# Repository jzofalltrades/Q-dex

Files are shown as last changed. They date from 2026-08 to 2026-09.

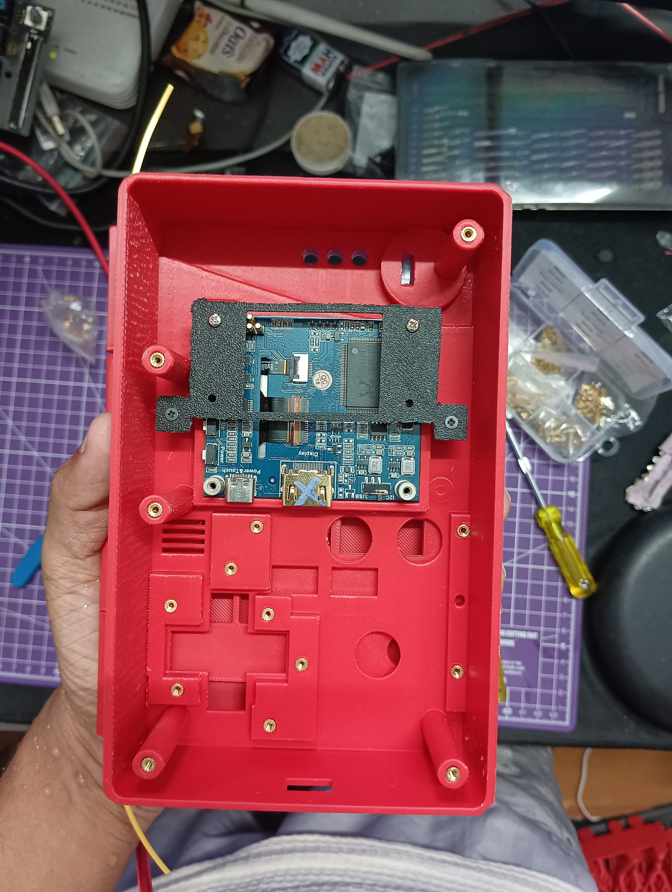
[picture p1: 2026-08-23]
images/build-backpanel-inserts.jpg

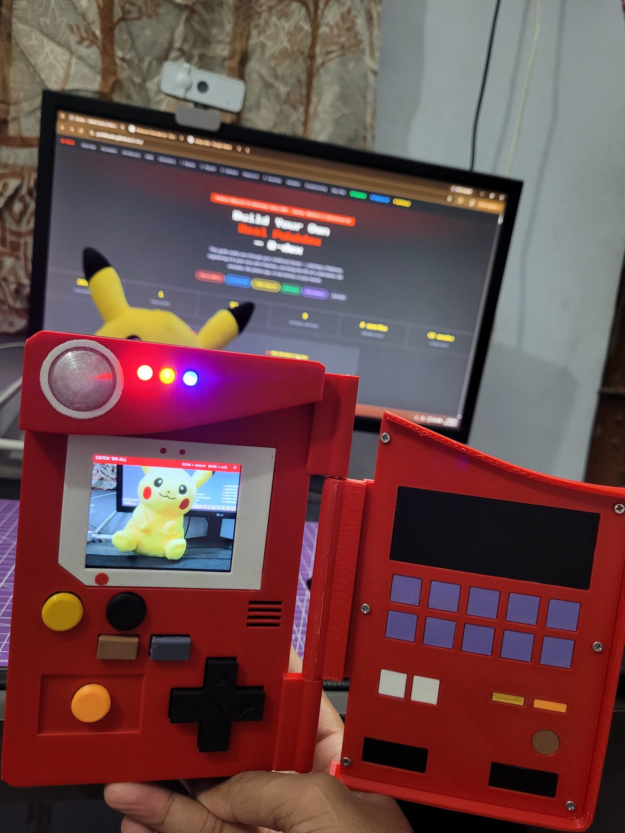
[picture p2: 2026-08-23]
images/mode-reverse-camera.jpg

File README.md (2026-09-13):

# Q-dexter — A Real Handheld Pokédex

A fully working handheld Pokédex built on the **Arduino UNO Q**, for the
**Arduino Physical AI Challenge India 2026**. Point it at a Pokémon, press
scan, and it identifies the creature, shows its Pokédex entry, speaks its
name, and logs the catch — with on-device AI, a voice assistant, and a
3D-printed Gen-1 Kanto shell.

### 🔗 Live pages
- **[📖 Full Build Guide](https://jzofalltrades.github.io/Q-dex/)** — the complete, illustrated how-to
- **[🎮 3D Model Viewer](https://jzofalltrades.github.io/Q-dex/viewer.html)** — rotate the enclosure in your browser

---

## What it does

- **Reverse Image Version** — camera capture → Google Lens → identifies any of
  the **1025 Pokémon**, shows stats/evolution/moves/location, speaks the entry,
  and records the catch.
- **PhyAI Challenge** — an **on-device** neural network (MobileNetV2, runs with
  no internet) that recognises four Pokémon (Bulbasaur, Charizard, Pikachu,
  Squirtle) live from the camera.
- **Professor Oak voice assistant** — ask questions out loud; on-device
  speech-to-text (whisper.cpp) → Claude → spoken reply. Knows your trainer
  profile and real catch progress.
- **Trainer system** — profiles, XP, levels, and **72 gym badges** across all
  9 regions, with region unlock gating.
- **Physical build** — 3D-printed Kanto-red shell, physical keypad, indicator
  LEDs, a blinking lens LED, and a real speaker.

## How it works

The device is an Arduino UNO Q (embedded Linux) running a pygame app, with an
ESP32-C3 handling the physical keypad and lens LED over USB serial. A camera
feeds both the online reverse-image path and the offline on-device classifier.
Audio is spoken through espeak into a PAM8403 amp and speaker.

```
Camera ─┬─► Reverse Image Version ─► Google Lens ─► Pokédex entry ─► speak + log
        └─► PhyAI (on-device model) ─► live identification

Mic ─► whisper.cpp ─► Claude ─► Professor Oak reply ─► speak
```

Full architecture, schematics, bill of materials, wiring, print settings, and
step-by-step build phases are in the **[Build Guide](https://jzofalltrades.github.io/Q-dex/)**.

## Repository layout

| Path | What it is |
|---|---|
| `pokedex_app.py` | The main pygame Pokédex application |
| `key_serial.py` | Host-side reader for the ESP32 keypad + LED forwarding |
| `keypad_serial.ino` | ESP32-C3 firmware (keypad + WS2812 lens LED) |
| `pokedex_phyai.tflite` | On-device Pokémon classifier (TFLite) |
| `labels.txt` | Class labels for the on-device model |
| `badges/` | All 72 gym-badge images, by region |
| `build_db.py`, `build_locations.py` | Database build scripts |
| `index.html`, `viewer.html` | The build-guide website and 3D viewer |
| `models/` | 3D model of the enclosure (`.glb`) |
| `cad/` | Fusion 360 / STL enclosure files |

## Hardware

Arduino UNO Q · ESP32-C3 Super Mini · USB camera · PAM8403 amplifier + speaker ·
WS2812 LED · indicator LEDs · 3D-printed enclosure. Full BOM in the build guide.

## License

This project's code and designs are released under the MIT License — see the LICENSE file. You're free to build your own, modify it, and share it, with credit.

**Non-commercial fan project.** Pokémon and all related names, data, and cries are trademarks of Nintendo / Game Freak / The Pokémon Company. Q-dex is an independent fan project, not affiliated with or endorsed by Nintendo, and may not be sold commercially.

## Built by

[jzofalltrades](https://github.com/jzofalltrades) — solo entry, Arduino
Physical AI Challenge India 2026.

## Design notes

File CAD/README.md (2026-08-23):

# Q-dex — CAD Files

3D-printable enclosure for the Q-dex handheld Pokédex, designed in Autodesk Fusion 360.

## Files

| File | Purpose |
|---|---|
| `STL/` | Ready-to-print meshes — load straight into your slicer. |
| `pokedexV4.step` | Editable, software-neutral CAD — open and modify in any CAD program. |
| `pokedexV4.f3d` | Original Fusion 360 project with full design history. |

## Parts (STL folder)

**Main body & lid**
- `LeftTub.stl` — main front body; holds the display, ESP32 keypad and buttons
- `BackPlate.stl` — back panel; mounts the Arduino UNO Q (brass-insert bosses)
- `RightLid.stl` — the right-hand lid of the clamshell
- `LidFacePlate.stl` — face plate for the lid
- `ScreenBezel.stl` — frames the 2.8" display
- `LCDCrossPlate.stl` — internal display support plate

**Buttons & caps**
- `Cap_DPad.stl` — one-piece D-pad cross cap
- `Cap_btn9.stl`, `Cap_Select.stl`, `Cap_Back.stl` — action-button caps
- `Cap_pillA.stl`, `Cap_pillB.stl` — pill-shaped button caps

**Lens**
- `Dome_Ring.stl` — ring that holds the clear dome lens (print the lens itself in clear PETG)

**Right-panel dummy inserts** (cosmetic, non-functional — they fill the decorative right panel)
- `DummyBtn_Mute_rightpanel.stl`, `DummyKey_rightpanel_x10.stl`, `DummyPill_rightpanel_x2.stl`,
  `Dummy_Screen_Right panel.stl`, `Dummy_bottom_rectangle_rightpanel_x2.stl`,
  `Dummy_bottomsquare_x2_rightpanel.stl`

## Print settings

- **Material:** PLA for every part **except** the dome lens, printed in **clear PETG** so the WS2812 lens LED shines through.
- **Layer height:** 0.20 mm for all parts.
- **Total print time:** approximately 25+ hours across the full set.
- **Hinge:** printed-in — there is no separate metal hinge pin.
- **Inserts / screws:** M2 and M3 brass heat-set inserts; screws M2×3 / M2×6 / M2×8 to match.

Print one button cap and its matching hole first as a quick fit test before committing to the long shell prints.

## Assembly

See the full build guide at **https://jzofalltrades.github.io/Q-dex/** (Phase 4 — Print & Assembly) and the interactive 3D model at **https://jzofalltrades.github.io/Q-dex/viewer.html**.

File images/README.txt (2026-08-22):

Q-dexter product photos — build shots, final device, screens in action.

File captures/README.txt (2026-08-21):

Camera captures are uploaded here at runtime for Google Lens recognition.

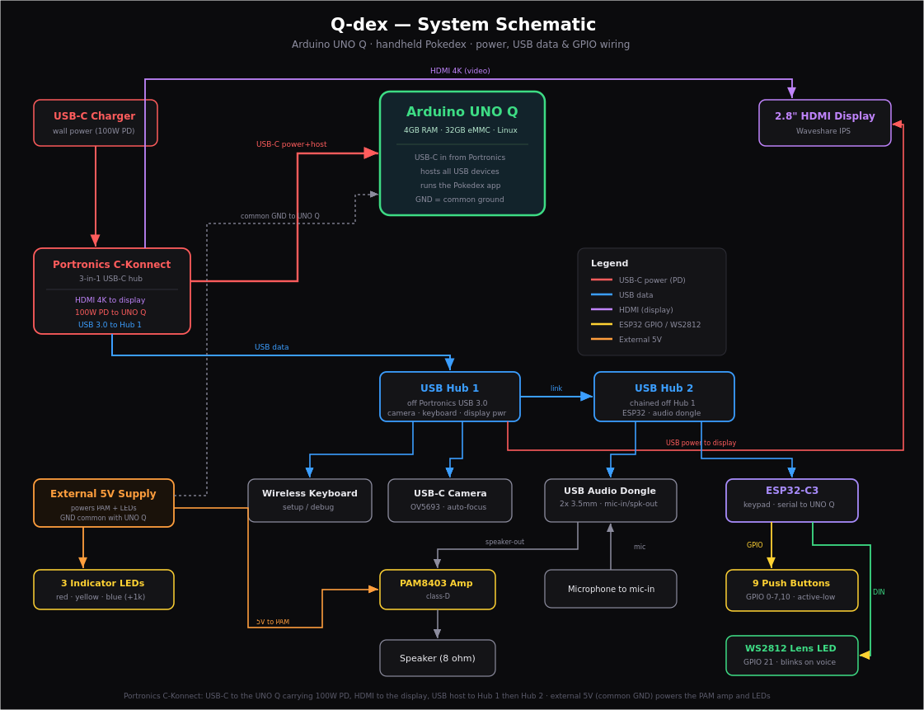
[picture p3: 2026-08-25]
images/qdex_schematic.png

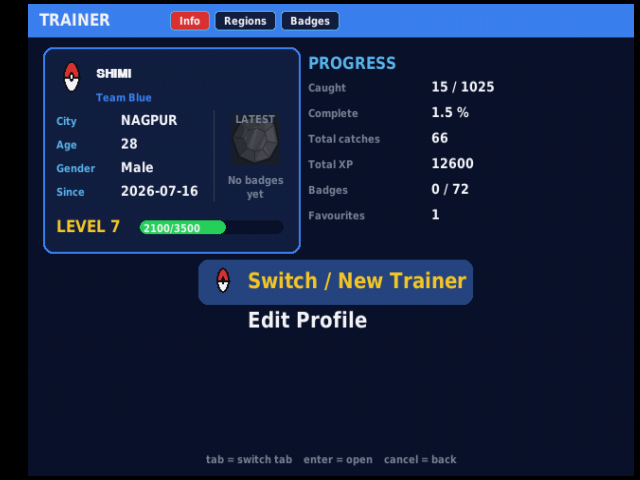
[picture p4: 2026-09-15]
images/screens/trainer-info.png

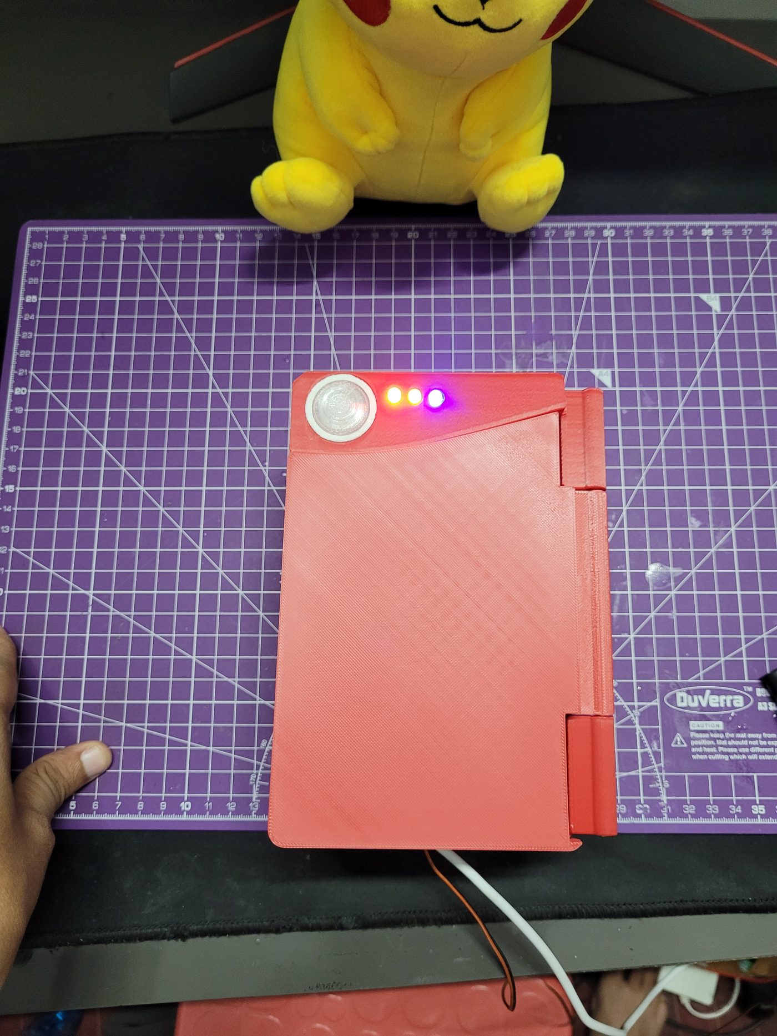
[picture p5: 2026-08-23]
images/device-closed-back.jpg

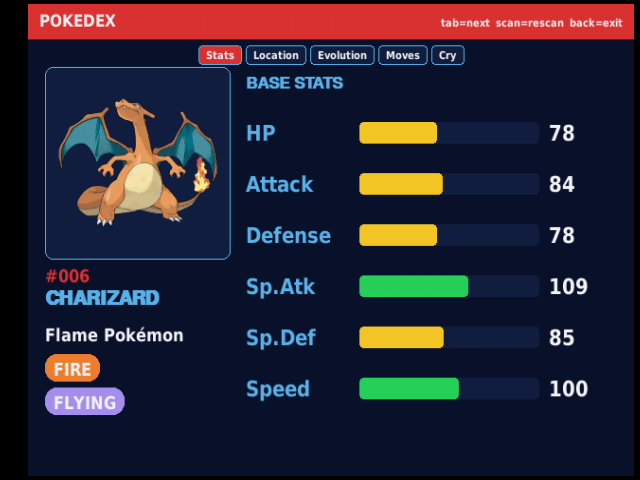
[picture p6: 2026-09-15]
images/screens/charizard-stats.gif

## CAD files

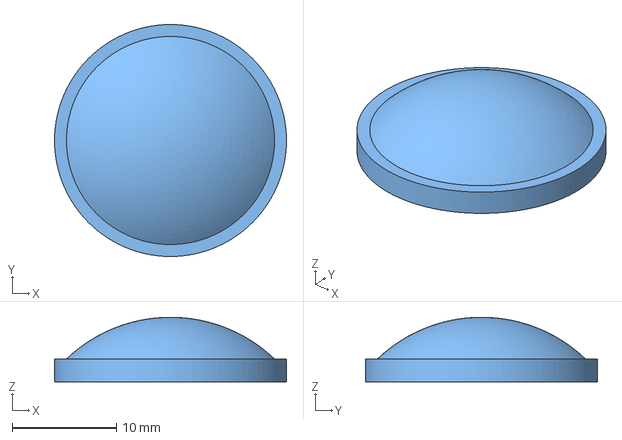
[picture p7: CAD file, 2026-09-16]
CAD/3mf/Dome_Lens.3mf
22.3 x 22.3 x 6.20 mm

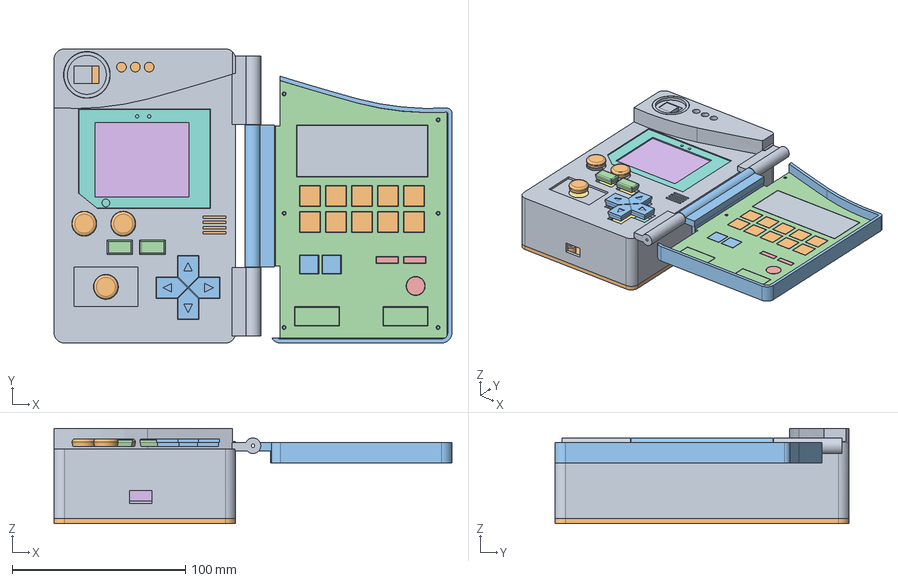
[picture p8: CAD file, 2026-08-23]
CAD/pokedexV4.step
230.0 x 170.0 x 55.0 mm

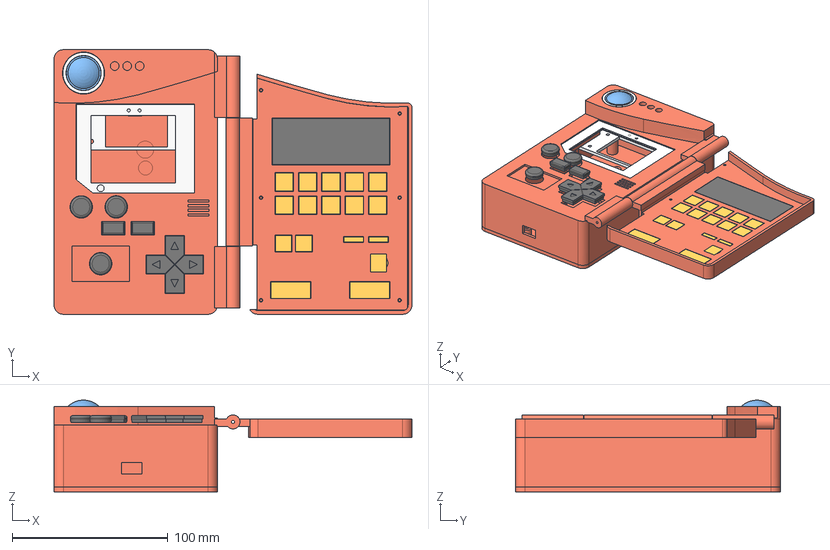
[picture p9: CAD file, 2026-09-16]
CAD/step/pokedex.step
230.0 x 170.0 x 59.0 mm

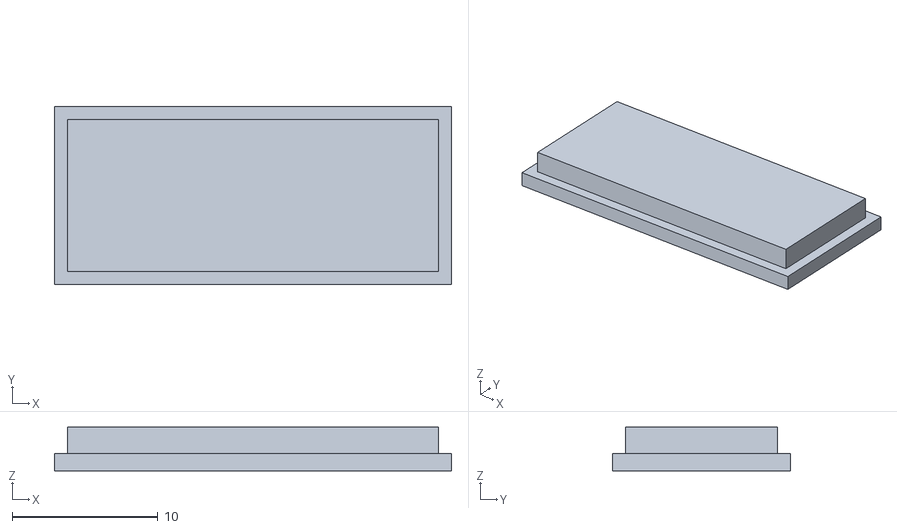
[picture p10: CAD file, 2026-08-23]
CAD/STL/Dummy_bottom_rectangle_rightpanel_x2.stl
27.2 x 12.2 x 3.00

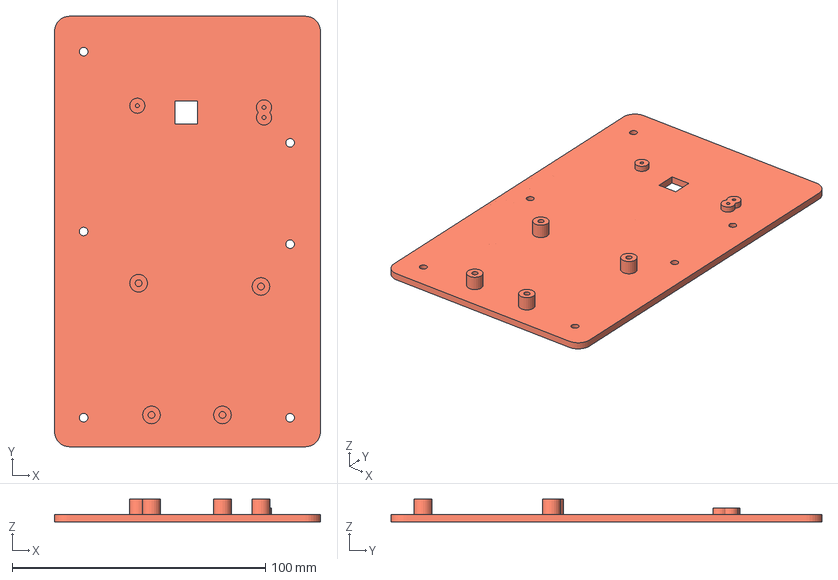
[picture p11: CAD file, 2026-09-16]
CAD/3mf/BackPlate.3mf
105.0 x 170.0 x 9.00 mm

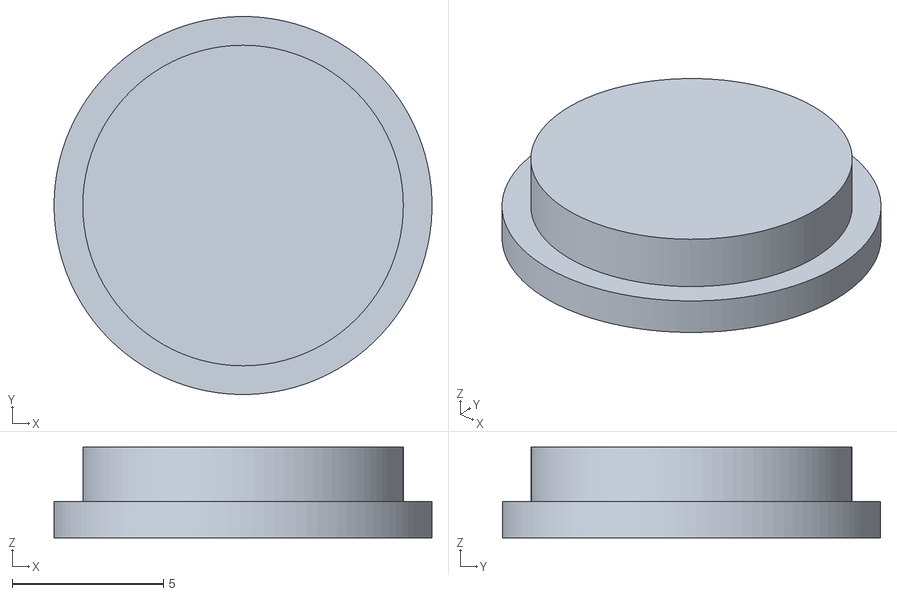
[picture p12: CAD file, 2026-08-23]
CAD/STL/DummyBtn_Mute_rightpanel.stl
12.5 x 12.5 x 3.00

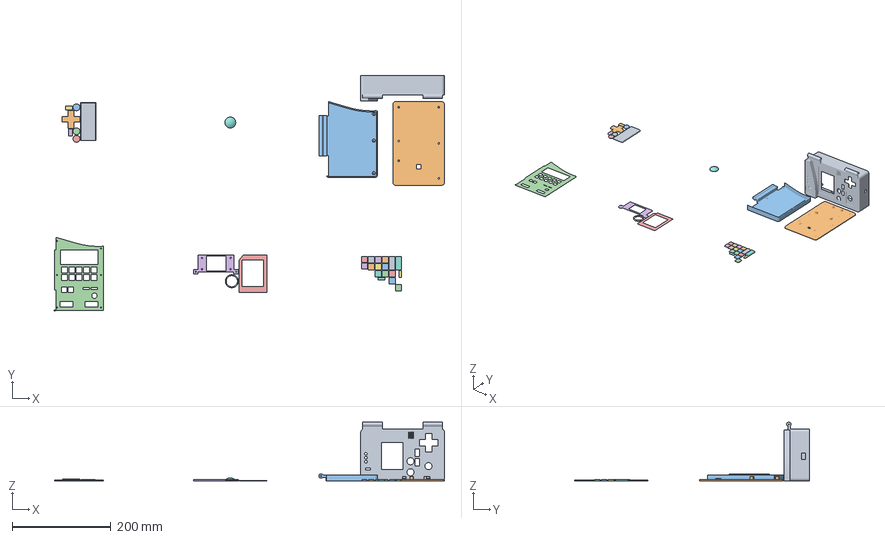
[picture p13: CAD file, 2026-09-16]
CAD/3mf/pokedex_1.3mf
791.5 x 477.1 x 119.5 mm
Dummy_Screen_R
Cap_DPad
Cap_Back
Cap_Select
Cap_btn9
Cap_pillB
Cap_pillA
Dome_Lens
LeftTub
BackPlate
RightLid
LidFacePlate
ScreenBezel
LCDCrossPlate
Dome_Ring
DummyBtn_Wide_139
DummyBtn_Wide_190
DummyKey_Bot_142
DummyKey_Bot_157
DummyKey_Bot_172
DummyKey_Bot_187
DummyKey_Bot_202
DummyKey_Top_142
DummyKey_Top_157
DummyKey_Top_172
DummyKey_Top_187
DummyKey_Top_202
DummyBtn_Mute
DummyBtn_Small_142
DummyBtn_Small_155
DummyPill_186
DummyPill_202

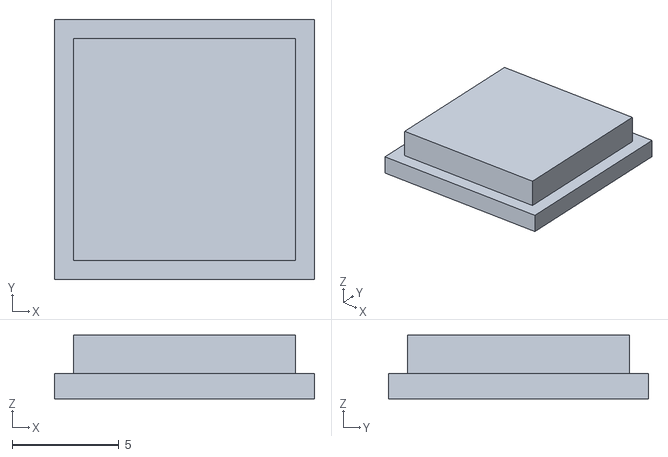
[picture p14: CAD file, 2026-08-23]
CAD/STL/Dummy_bottomsquare_x2_rightpanel.stl
12.2 x 12.2 x 3.00

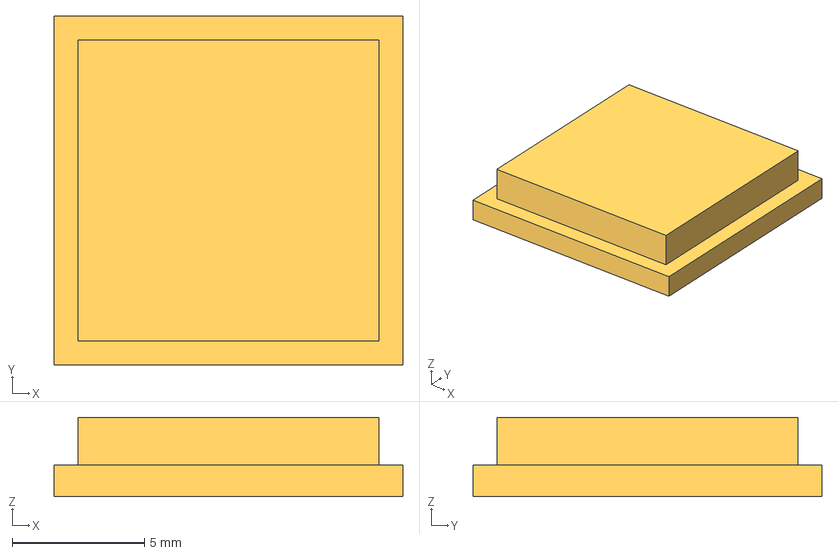
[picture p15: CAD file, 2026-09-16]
CAD/3mf/DummyKey_Top_157.3mf
13.2 x 13.2 x 3.00 mm

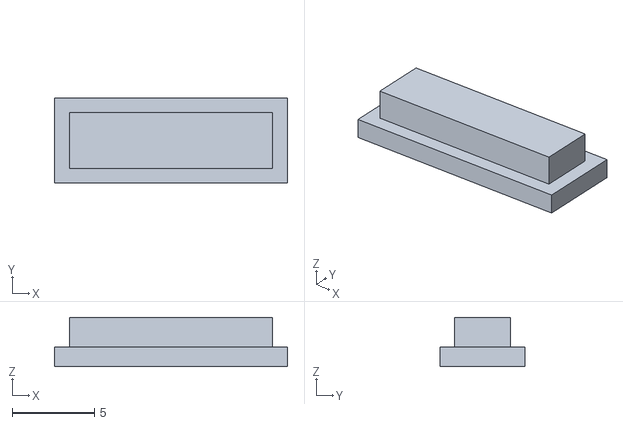
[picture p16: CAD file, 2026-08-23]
CAD/STL/DummyPill_rightpanel_x2.stl
14.2 x 5.20 x 3.00

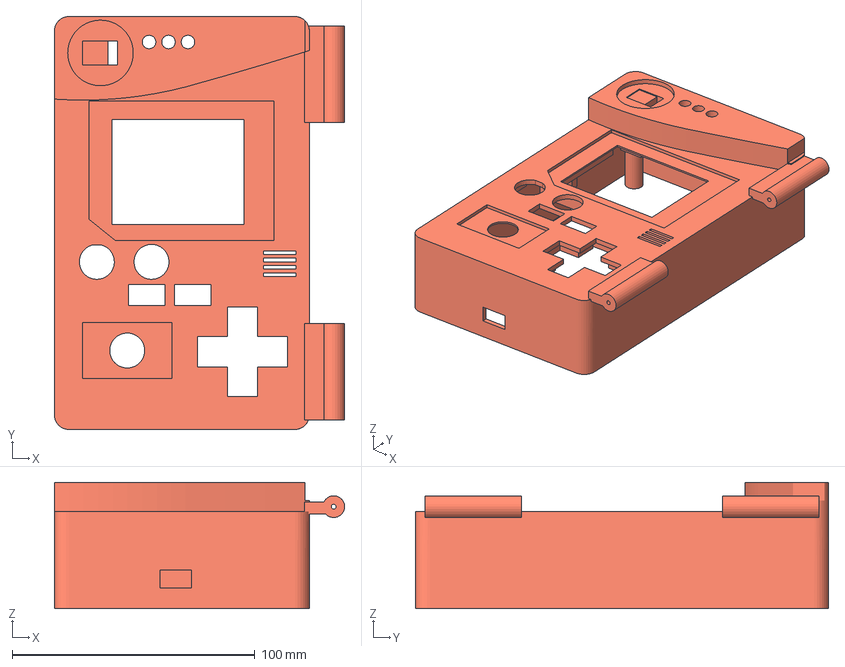
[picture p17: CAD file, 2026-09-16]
CAD/3mf/LeftTub.3mf
119.5 x 170.0 x 52.0 mm

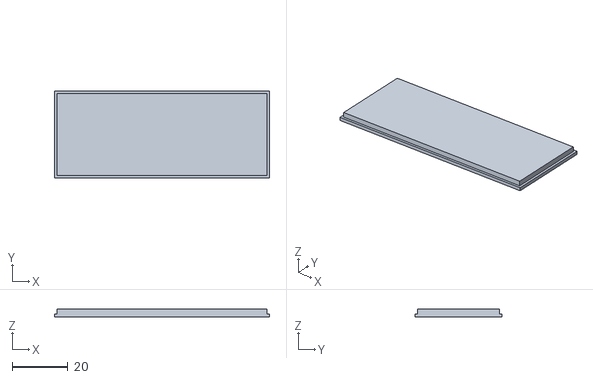
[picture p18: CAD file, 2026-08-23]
CAD/STL/Dummy_Screen_Right panel.stl
77.2 x 31.2 x 3.00

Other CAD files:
CAD/STL/DummyKey_rightpanel_x10.stl
CAD/3mf/DummyPill_202.3mf
CAD/3mf/DummyKey_Top_172.3mf
CAD/3mf/DummyKey_Bot_202.3mf
CAD/3mf/DummyKey_Bot_157.3mf
CAD/3mf/DummyBtn_Small_155.3mf
CAD/3mf/Cap_Back.3mf
CAD/3mf/Cap_DPad.3mf
CAD/3mf/Cap_Select.3mf
CAD/3mf/Cap_btn9.3mf
CAD/3mf/Cap_pillA.3mf
CAD/3mf/Cap_pillB.3mf
CAD/3mf/Dome_Ring.3mf
CAD/3mf/DummyBtn_Mute.3mf
CAD/3mf/DummyBtn_Small_142.3mf
CAD/3mf/DummyBtn_Wide_139.3mf
CAD/3mf/DummyBtn_Wide_190.3mf
CAD/3mf/DummyKey_Bot_142.3mf
CAD/3mf/DummyKey_Bot_172.3mf
CAD/3mf/DummyKey_Bot_187.3mf
CAD/3mf/DummyKey_Top_142.3mf
CAD/3mf/DummyKey_Top_187.3mf
CAD/3mf/DummyKey_Top_202.3mf
CAD/3mf/DummyPill_186.3mf
CAD/3mf/Dummy_Screen_R.3mf
CAD/3mf/LCDCrossPlate.3mf
CAD/3mf/LidFacePlate.3mf
CAD/3mf/RightLid.3mf
CAD/3mf/ScreenBezel.3mf
CAD/3mf/pokedex.3mf
CAD/3mf/pokedex.f3d
CAD/3mf/pokedex.stl
CAD/3mf/pokedexV6.step
CAD/f3d/pokedex.f3d
CAD/pokedexV4.f3d
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

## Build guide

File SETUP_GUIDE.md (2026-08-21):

# Pokédex — Complete Setup Guide (from scratch)

Everything needed to take a blank Arduino UNO Q to a working Pokédex.
Written so you can come back in six months and follow it without remembering
anything.

Device is called **shimi**. User `arduino`, password `arduino`.
All app files live in **`~/pokedexv5/`**.

---

## 0. What this thing is

Point the camera at a Pokémon card or figure, press SCAN. It uploads the photo,
reverse-image-searches it with Google Lens, matches the result against a local
1025-Pokémon database, then shows the stats on screen and speaks the name out
loud. Every catch is saved forever in a local database.

Nine physical buttons drive everything. No touchscreen, no keyboard.

---

## 1. Hardware

| Part | Purpose | Notes |
|---|---|---|
| Arduino UNO Q | the brain | Linux side runs everything |
| Waveshare 2.8" HDMI LCD | screen | 640×480, via USB-C PD hub |
| Arducam UB0238 USB camera | eyes | shows up as "Hy-Usb2.0" |
| ESP32-C3 Super Mini | 9 buttons | connects to shimi by **USB** |
| PAM8403 amp + 2 speakers | sound | **separate 5V supply** |
| USB PnP sound card | audio out | |

### The one rule that will burn you

**The PAM8403 amplifier must have its own 5V supply** (phone charger or power
bank). Share only the GND wire with the UNO Q.

If you power the amp from the UNO Q, the whole board browns out and shuts down
the moment audio plays. This looks like a random crash and you will waste an
hour on it.

### Buttons

Each button: one leg → its GPIO, other leg → GND. No resistors (internal
pull-ups). 2-pin tactile buttons have no polarity — either leg either way.

| Button | GPIO | Does |
|---|---|---|
| enter | 0 | select / open |
| cancel | 1 | back |
| tab | 2 | switch tab / region |
| up | 3 | move up |
| down | 4 | move down |
| right | 5 | next tab / region |
| left | 6 | prev tab / region |
| pageleft | 7 | **SCAN** |
| pageright | 10 | back |

GPIO 2 is a strapping pin. If `tab` misbehaves or the board won't boot, move it
to GPIO 21 (change the wire *and* the sketch).

---

## 2. Flash the keypad

1. Open `keypad_serial.ino` in Arduino IDE
2. Board: **ESP32C3 Dev Module**
3. **Tools → USB CDC On Boot → Enabled** ← miss this and serial won't work
4. Upload

Test it: open Serial Monitor at 115200, press buttons. Each should print its
name (`enter`, `up`, `pageleft`...). If a button fires on its own, that pin is
floating — check the wire.

Then plug the ESP32 into shimi's USB. It becomes `/dev/ttyACM0`.

---

## 3. First-time system setup on shimi

SSH in from your laptop:

```bash
ssh arduino@192.168.1.56
```

### Storage — read this before installing anything

The 32GB eMMC is split into two partitions:

- `/` (system) — **10GB, nearly full**
- `/home/arduino` — **18GB, mostly empty**

pip installs to `/` by default and fills it, then everything fails with
`No space left on device`. Always install like this:

```bash
mkdir -p /home/arduino/tmp
TMPDIR=/home/arduino/tmp pip3 install --user --break-system-packages <package>
```

Never install full `torch` — it drags in 500MB+ of NVIDIA CUDA libraries that
are useless here (no NVIDIA GPU) and will fill the disk.

If you run out of space:
```bash
pip3 cache purge
sudo apt clean
df -h /
```

### Install the packages

```bash
mkdir -p /home/arduino/tmp
TMPDIR=/home/arduino/tmp pip3 install --user --break-system-packages \
  pygame opencv-python requests rapidfuzz google-search-results pyserial pillow
```

### Static IP

Stops the IP changing on every reboot. Uses the 2.4GHz network:

```bash
nmcli device wifi connect "FTTH" password "12345678"
sudo nmcli connection modify FTTH ipv4.addresses 192.168.1.56/24
sudo nmcli connection modify FTTH ipv4.gateway 192.168.1.1
sudo nmcli connection modify FTTH ipv4.dns "8.8.8.8 1.1.1.1"
sudo nmcli connection modify FTTH ipv4.method manual
sudo nmcli connection down FTTH && sudo nmcli connection up FTTH
```

Verify — should say `proto static`:
```bash
hostname -I
ip route | grep default
```

### Landscape screen, permanently

Without this the screen boots portrait every time:

```bash
sudo mkdir -p /etc/X11/xorg.conf.d
sudo tee /etc/X11/xorg.conf.d/90-rotate.conf > /dev/null << 'EOF'
Section "Monitor"
    Identifier "DP-1"
    Option "Rotate" "left"
EndSection
EOF
sudo reboot
```

### Stop Arduino App Lab auto-launching

It opens over your app on every boot:

```bash
mkdir -p ~/.config/autostart
cat > ~/.config/autostart/ArduinoAppLab.desktop << 'EOF'
[Desktop Entry]
Type=Application
Name=Arduino App Lab
Exec=arduino-app-lab
Hidden=true
X-XFCE-Autostart-Enabled=false
NoDisplay=true
EOF
```

`Hidden=true` alone isn't enough on XFCE — you need
`X-XFCE-Autostart-Enabled=false` too.

Leave `arduino-router.service` and `arduino-app-cli.service` running. They're
background daemons, not the GUI, and other things depend on them.

### Audio volume

```bash
amixer -c 1 cset numid=6 100%
amixer -c 1 cset numid=5 1
```

(`-c 1` = the USB card. Check with `aplay -l` — the app auto-detects it, but
`amixer` needs the number.)

---

## 4. Get the files onto shimi

Unzip the package on your laptop, then from PowerShell:

```powershell
scp -r C:\path\to\pokedexv5 arduino@192.168.1.56:/home/arduino/
```

`scp -r` nests folders if the target exists. Check and flatten if needed:

```bash
ls -R ~/pokedexv5/
# if you see ~/pokedexv5/pokedexv5/ :
mv ~/pokedexv5/pokedexv5/* ~/pokedexv5/ && rmdir ~/pokedexv5/pokedexv5
```

### Your SerpAPI key

```bash
nano ~/pokedexv5/serp_key.txt
```

Paste the key (nothing else, no quotes). Ctrl+O, Enter, Ctrl+X.

```bash
chmod 600 ~/pokedexv5/serp_key.txt
```

Get a key free at serpapi.com — 250 searches/month. Check what's left:
```bash
curl -s "https://serpapi.com/account?api_key=$(cat ~/pokedexv5/serp_key.txt)"
```

---

## 5. Build the database (once, ~40 min)

Only if `~/pokedex/pokemon_db.json` doesn't already exist.

```bash
mkdir -p ~/pokedex
python3 ~/pokedexv5/build_db.py            # ~40 min, 1025 pokemon
python3 ~/pokedexv5/download_ui_images.py  # all 1025 artwork PNGs
```

Run them in two terminals at once to save time. `download_ui_images.py` skips
files it already has, so re-run it if it dies partway.

Verify:
```bash
python3 -c "
import json
db=json.load(open('/home/arduino/pokedex/pokemon_db.json'))
print('pokemon:', len(db))
b=db['bulbasaur']
print('fields:', sorted(b.keys()))
"
ls ~/pokedex/ui_images/ | wc -l    # should be 1025
```

Both live in `~/pokedex/` and are shared — the app reads them from there.

### Location data (optional, ~30 min)

The Location tab needs encounter data, which isn't in the base database:

```bash
python3 ~/pokedexv5/build_locations.py
```

Safe to re-run — it skips pokemon it already did and saves every 25, so if it
dies partway just run it again. Without it the Location tab says "No location
data". Many pokemon legitimately have none (evolutions, legendaries, starters)
and show "Not found in the wild".

---

## 6. Check everything

```bash
bash ~/pokedexv5/setup.sh
```

Every line should say `[OK]`. Fix any `[MISS]` before running.

---

## 7. Run it

Two terminals.

**Terminal 1 — keypad:**
```bash
python3 ~/pokedexv5/key_serial.py
```
Leave it running. Every button press prints its name here.

**Terminal 2 — the app:**
```bash
export DISPLAY=:0
python3 ~/pokedexv5/pokedex_app.py
```

**Kill both:**
```bash
pkill -9 -f pokedex_app.py; pkill -9 -f key_serial.py
```

---

## 8. Using it

```
Main Menu
├── Reverse Image Version
│   ├── Play Catch 'Em All    camera starts HERE (not before)
│   ├── Pokedex List          all 1025 by region, caught ones green
│   ├── Search by Name        letter grid
│   ├── Favourites            starred pokemon
│   ├── Caught Pokemon        completion %, most caught, latest
│   ├── Catch Log             every catch, newest first
│   └── Back
├── PhyAI Challenge           placeholder
├── Trainer Status            profile, level, badges, switch trainer
└── Data                      erase catches / erase everything
```

**First run:** there's no trainer yet. Open **Trainer Status** and it walks you
through creating one — name, city, age, gender, team (Red / Blue / Yellow).
Name and city use the letter grid: dpad moves, **enter** picks, DONE finishes.
**cancel** goes back a step.

**Catch 'Em All:** aim using the live feed, **pageleft** to scan. The scan
screen freezes on the exact photo being uploaded. On a hit you get the tabbed
result (Stats / Location / Evolution / Moves / Cry), it speaks the name,
records the catch, and shows an XP toast. **back** returns to the live feed;
**back** again exits to the menu.

**Pokedex List:** up/down scrolls, **tab** switches region, **enter** opens.

**Any detail screen:** **tab** or left/right cycles tabs, **enter** stars the
pokemon as a favourite, **cancel** goes back.

**Caught Pokemon:** **tab** cycles the sort — Dex No. / Most Caught / Recent.

**Trainer Status:** three tabs, **tab** cycles them.
- **Info** — profile card, level, XP bar, totals, and the menu (switch trainer,
  edit profile, How to Play)
- **Regions** — all 9 with progress bars and the 60% unlock marker
- **Badges** — all 72, locked ones grey

In the trainer list, **tab** deletes a trainer (with confirmation).

### XP and levels

| Event | XP |
|---|---|
| Catch a pokemon | 100 |
| First time catching that species | +400 bonus |

Level N costs `500 × N` XP. Caps at level 50.

### Badges — 72 across 9 regions

Every region is always playable. What locks is a region's **badge set**: catch
**60%** of a region to unlock its 8 badges, then each badge has its own
requirement (catch a specific pokemon / catch N from the region / complete the
regional dex).

| Region | Need | of |
|---|---|---|
| Kalos | 44 | 72 |
| Alola | 53 | 88 |
| Galar | 58 | 96 |
| Johto | 60 | 100 |
| Sinnoh | 65 | 107 |
| Paldea | 72 | 120 |
| Hoenn | 81 | 135 |
| Kanto | 91 | 151 |
| Unova | 94 | 156 |

Full badge tables are in **GAME_MANUAL.md**, and the same content is in the
app under Trainer → Info → How to Play.

### Badge art

Drawn by the app as original shapes — real names and colours, not Nintendo's
artwork. To use your own, drop PNGs in `~/pokedexv5/badges/` named after the
badge (`boulder_badge.png`). Missing files fall back to the drawn shape.

### Data

**Erase my catches** — wipes the current trainer's catches, XP, badges and
favourites. Keeps the profile.
**Erase EVERYTHING** — every trainer, every catch. Back to a blank device.

Both ask for confirmation first.

Everything is saved to `~/pokedexv5/catches.db` (SQLite) and survives reboots.
Multiple trainers share the one file — each keeps their own catches.

---

## 9. Why things are built the way they are

Read this before "fixing" any of it.

### The keypad is USB, not WiFi

The router has **AP/client isolation** — WiFi devices can't talk to each other.
shimi and the ESP32 both get internet but can't ping each other (100% loss).
The old WiFi keypad returned `HTTP -1` forever because of this.

USB serial sidesteps the network entirely. Don't switch it back to WiFi unless
you can disable isolation on the router.

### The image host is litterbox

SerpApi's Google Lens API **only accepts publicly-hosted image URLs**. File
upload isn't supported (open feature request, years old). So the capture has to
be uploaded somewhere public first.

Hosts that stopped working — Google Lens silently returns **0 matches**:
- tmpfiles.org
- catbox.moe

Hosts that don't work here:
- imgur — blocked in India
- 0x0.st — unreachable from this network
- AWS S3 — Lens has known trouble with S3 URLs

Works: **litterbox.catbox.moe** (verified, 60 matches). Files expire in 1h,
which is fine — the URL only needs to survive one search.

GitHub raw URLs also work (verified, 59 matches) if litterbox ever dies. That
needs a repo + a **classic** token with the `repo` scope. Fine-grained tokens
with "public repositories" are read-only and give a confusing **404** (not 403)
on write.

### Camera and audio auto-detect

Both device numbers shift between reboots:
- Camera: `/dev/video0` one boot, `/dev/video1` or `video2` the next
- Audio: `card 0` or `card 1`

The camera is trickier — **two** devices match "Hy-" (e.g. video1 and video4)
but only one actually returns frames. `find_camera()` tries each and keeps the
one that delivers a real frame. `find_audio()` parses `aplay -l` and prefers
the USB card.

Never hardcode either.

### Camera needs MJPEG

Without this the camera opens but returns nothing:
```python
cap = cv2.VideoCapture(dev, cv2.CAP_V4L2)
cap.set(cv2.CAP_PROP_FOURCC, cv2.VideoWriter_fourcc('M','J','P','G'))
```

### The 5-frame flush

The camera buffers frames. Without flushing, a scan captures a stale frame from
several seconds ago — you'd aim at a Pokémon and it would upload a photo of
your hand. So before capturing:
```python
for _ in range(5): self.cap.read()
ret, frame = self.cap.read()
```

### SDL_AUDIODRIVER=dummy

This line must be at the very **top** of the app, before `import pygame`:
```python
os.environ['SDL_AUDIODRIVER'] = 'dummy'
```
Otherwise pygame grabs the audio device and espeak/aplay can't use it.

---

## 10. When it breaks

### "Pokemon not found" every time

Look at what the camera actually sent:
```bash
export DISPLAY=:0
ristretto ~/pokedexv5/capture.jpg
```

- **Wrong thing in frame** (your hand, etc.) → the flush isn't working
- **Blurry / dark** → aim and lighting
- **Looks fine** → the host died. Test it:

```bash
cd ~/pokedexv5 && python3 -c "
import requests, time
from serpapi import GoogleSearch
KEY=open('serp_key.txt').read().strip()
u=requests.post('https://litterbox.catbox.moe/resources/internals/api.php',
  data={'reqtype':'fileupload','time':'1h'},
  files={'fileToUpload':open('capture.jpg','rb')}).text.strip()
print('url:', u); time.sleep(2)
r=GoogleSearch({'engine':'google_lens','url':u,'api_key':KEY}).get_dict()
print('matches:', len(r.get('visual_matches',[])))
"
```

Confirm it's the host, not the image, with a URL known to work:
```bash
cd ~/pokedexv5 && python3 -c "
from serpapi import GoogleSearch
KEY=open('serp_key.txt').read().strip()
r=GoogleSearch({'engine':'google_lens','api_key':KEY,
 'url':'https://raw.githubusercontent.com/PokeAPI/sprites/master/sprites/pokemon/other/official-artwork/25.png'}).get_dict()
print('matches:', len(r.get('visual_matches',[])))
"
```
59-ish matches = SerpAPI is fine, your host is dead → find a new one.
0 matches = SerpAPI or quota problem.

Check quota:
```bash
curl -s "https://serpapi.com/account?api_key=$(cat ~/pokedexv5/serp_key.txt)" | grep searches_left
```

### UNO Q shuts down when audio plays
The amp is on the UNO Q's power. Give it its own 5V supply. Only GND shared.

### No audio
```bash
aplay -l                                    # find the USB card number
espeak -a 200 "test" --stdout | aplay -D plughw:1,0
cd ~/pokedexv5 && python3 -c "
import sys; sys.path.insert(0,'.')
from pokedex_app import AUDIO_DEV; print('detected:', AUDIO_DEV)"
```
If espeak works but the app is silent, `AUDIO_DEV` detected wrong.

### Camera black / won't open
```bash
v4l2-ctl --list-devices
cd ~/pokedexv5 && python3 -c "
import sys; sys.path.insert(0,'.')
from pokedex_app import find_camera; print(find_camera())"
```
Should print the Hy- device that actually works.

### Keypad dead
```bash
ls /dev/ttyACM*          # should exist
fuser /dev/ttyACM0       # something else holding it?
```
Close the Arduino IDE Serial Monitor — it holds the port.
Button names print but nothing happens → that screen doesn't use that button.

### Can't SSH / password rejected
IP probably changed. On the HDMI screen:
```bash
hostname -I
whoami
```
Then redo the static IP (section 3).

### Screen is portrait
```bash
DISPLAY=:0 xrandr --output DP-1 --rotate left      # right now
```
Permanent fix is `/etc/X11/xorg.conf.d/90-rotate.conf` (section 3).

### No space left on device
```bash
df -h              # look at / vs /home/arduino
pip3 cache purge
sudo apt clean
```
Reinstall with `TMPDIR=/home/arduino/tmp pip3 install --user --break-system-packages`.

---

## 11. Files

```
~/pokedexv5/
├── pokedex_app.py          the whole app
├── key_serial.py           keypad reader
├── keypad_serial.ino       flash to ESP32-C3
├── build_db.py             only if DB missing
├── download_ui_images.py   only if images missing
├── build_locations.py      adds Location tab data
├── setup.sh                pre-flight check
├── GAME_MANUAL.md          the game: badges, regions, strategy
├── badges/                 optional: your own badge PNGs
├── serp_key.txt            YOUR key (create it)
├── catches.db              made on first catch
└── capture.jpg             latest camera frame

~/pokedex/                  shared, built once
├── pokemon_db.json         1025 pokemon
└── ui_images/              1025 PNGs
```

Inside `pokedex_app.py`:
- `CatchDB` — trainers, catches, XP, favourites, log, badges (one SQLite file)
- `level_from_xp()` — XP curve
- `REGION_RANGE` / `BADGES_BY_REGION` / `badge_earned()` — the 72 badges
- `draw_badge()` — draws all 20 badge shapes
- `TextInput` / `NumberInput` / `ChoiceInput` — dpad-driven input widgets
- `draw_pokeball()` / `draw_star()` — cursor and favourite marker
- `find_camera()` / `find_audio()` — device detection
- `upload_image()` — litterbox
- `search_image()` / `extract_candidates()` / `match_pokemon()` — recognition
- `App` — every screen as an `h_*` handler

### Upgrading from an older build

The database migrates itself. An old `catches` table with no trainer column
gets moved onto a profile called "Trainer" on first run, so nothing is lost.

---

## 12. Quick reference

```bash
# run
python3 ~/pokedexv5/key_serial.py                            # terminal 1
export DISPLAY=:0 && python3 ~/pokedexv5/pokedex_app.py      # terminal 2

# kill
pkill -9 -f pokedex_app.py; pkill -9 -f key_serial.py

# check
bash ~/pokedexv5/setup.sh
v4l2-ctl --list-devices
aplay -l
ls /dev/ttyACM*
hostname -I
df -h

# shutdown
sudo shutdown now
```

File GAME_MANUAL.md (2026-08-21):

# POKÉDEX — Game Manual

A real Pokédex. Point it at a Pokémon, press SCAN, and it identifies what
it's looking at, tells you about it, and records the catch forever.

Nine regions. 1025 Pokémon. 72 gym badges.

---

## How catching works

There's no random encounter, no wild grass. **You find the Pokémon in the real
world.** A card, a figure, a plush, a picture on a screen, a poster. If a
camera can see it and Google can recognise it, you can catch it.

1. **Main Menu → Reverse Image Version → Play Catch 'Em All**
2. Aim using the live feed on screen
3. Press **PAGELEFT** to scan
4. The screen freezes on the exact photo it's checking
5. On a hit: full Pokédex entry, spoken name, catch recorded, XP awarded

Press **BACK** once to return to the camera, twice to leave.

If it says "Pokemon not found", the photo wasn't clear enough or the image
search didn't recognise it. Better light, less glare, fill more of the frame.

---

## XP and levels

| Event | XP |
|---|---|
| Catch any Pokémon | 100 |
| **First time** catching that species | **+400 bonus** |

So a brand new species is worth **500**, a repeat is worth **100**.

Level N costs `500 × N` XP:

| Level | XP for that level | Total XP |
|---|---|---|
| 2 | 500 | 500 |
| 3 | 1,000 | 1,500 |
| 4 | 1,500 | 3,000 |
| 5 | 2,000 | 5,000 |
| 10 | 4,500 | 22,500 |
| 50 (max) | 24,500 | 612,500 |

**Chasing new species levels you 5× faster than re-scanning the same Charizard.**

---

## The nine regions

Every region is open from the very start. Browse any of them, catch anything
in any of them, in any order. Nothing is hidden behind anything else.

| Region | Pokédex | Dex range |
|---|---|---|
| Kanto | 151 | 1–151 |
| Johto | 100 | 152–251 |
| Hoenn | 135 | 252–386 |
| Sinnoh | 107 | 387–493 |
| Unova | 156 | 494–649 |
| Kalos | 72 | 650–721 |
| Alola | 88 | 722–809 |
| Galar | 96 | 810–905 |
| Paldea | 120 | 906–1025 |

---

## Unlocking a region's badges

What locks isn't the region — it's the **badges**.

> **Catch 60% of a region to unlock its 8 gym badges.**

Until then, that region's badges stay grey no matter what you catch. Once you
cross the line, every badge you already qualify for lands at once.

**The exact numbers:**

| Region | Need | of | Difficulty |
|---|---|---|---|
| **Kalos** | **44** | 72 | easiest — start here |
| Alola | 53 | 88 | |
| Galar | 58 | 96 | |
| Johto | 60 | 100 | |
| Sinnoh | 65 | 107 | |
| Paldea | 72 | 120 | |
| Hoenn | 81 | 135 | |
| Kanto | 91 | 151 | the classic |
| **Unova** | **94** | 156 | hardest |

The yellow line on each region's progress bar (Trainer → Regions) marks the
unlock point.

---

## Earning individual badges

Once a region is unlocked, each of its 8 badges has its own requirement:

- **Catch a specific Pokémon** — Thunder Badge needs Pikachu
- **Catch a number from that region** — Cascade Badge needs 25 Kanto
- **Complete the whole regional dex** — Earth Badge needs all 151

### Kanto — needs 91/151 to unlock

| Badge | Leader | Requirement |
|---|---|---|
| Boulder | Brock | Catch Geodude |
| Cascade | Misty | Catch 25 Kanto Pokémon |
| Thunder | Surge | Catch Pikachu |
| Rainbow | Erika | Catch 75 Kanto Pokémon |
| Soul | Koga | Catch Gastly |
| Marsh | Sabrina | Catch Abra |
| Volcano | Blaine | Catch Charizard |
| Earth | Giovanni | Complete the Kanto Pokédex (151) |

### Johto — needs 60/100

| Badge | Leader | Requirement |
|---|---|---|
| Zephyr | Falkner | Catch Hoothoot |
| Hive | Bugsy | Catch Ledyba |
| Plain | Whitney | Catch 20 Johto Pokémon |
| Fog | Morty | Catch Misdreavus |
| Storm | Chuck | Catch 40 Johto Pokémon |
| Mineral | Jasmine | Catch Magnemite |
| Glacier | Pryce | Catch Swinub |
| Rising | Clair | Complete the Johto Pokédex (100) |

### Hoenn — needs 81/135

| Badge | Leader | Requirement |
|---|---|---|
| Stone | Roxanne | Catch Geodude |
| Knuckle | Brawly | Catch 25 Hoenn Pokémon |
| Dynamo | Wattson | Catch Electrike |
| Heat | Flannery | Catch Numel |
| Balance | Norman | Catch 60 Hoenn Pokémon |
| Feather | Winona | Catch Swablu |
| Mind | Tate & Liza | Catch Spoink |
| Rain | Wallace | Complete the Hoenn Pokédex (135) |

### Sinnoh — needs 65/107

| Badge | Leader | Requirement |
|---|---|---|
| Coal | Roark | Catch Cranidos |
| Forest | Gardenia | Catch 25 Sinnoh Pokémon |
| Cobble | Maylene | Catch Riolu |
| Fen | Crasher Wake | Catch 50 Sinnoh Pokémon |
| Relic | Fantina | Catch Drifloon |
| Mine | Byron | Catch Shieldon |
| Icicle | Candice | Catch Snover |
| Beacon | Volkner | Complete the Sinnoh Pokédex (107) |

### Unova — needs 94/156

| Badge | Leader | Requirement |
|---|---|---|
| Trio | Striaton | Catch 15 Unova Pokémon |
| Basic | Lenora | Catch Lillipup |
| Insect | Burgh | Catch Sewaddle |
| Bolt | Elesa | Catch Blitzle |
| Quake | Clay | Catch 60 Unova Pokémon |
| Jet | Skyla | Catch Ducklett |
| Freeze | Brycen | Catch Cubchoo |
| Legend | Drayden | Complete the Unova Pokédex (156) |

### Kalos — needs 44/72 ← easiest region

| Badge | Leader | Requirement |
|---|---|---|
| Bug | Viola | Catch Scatterbug |
| Cliff | Grant | Catch 15 Kalos Pokémon |
| Rumble | Korrina | Catch Lucario |
| Plant | Ramos | Catch Chespin |
| Voltage | Clemont | Catch Dedenne |
| Fairy | Valerie | Catch Flabébé |
| Psychic | Olympia | Catch 45 Kalos Pokémon |
| Iceberg | Wulfric | Complete the Kalos Pokédex (72) |

### Alola — needs 53/88

Alola has island trials instead of gyms.

| Trial | Captain | Requirement |
|---|---|---|
| Melemele | Ilima | Catch Yungoos |
| Akala | Lana | Catch 15 Alola Pokémon |
| Fire | Kiawe | Catch Salandit |
| Grass | Mallow | Catch Fomantis |
| Electric | Sophocles | Catch Charjabug |
| Ghost | Acerola | Catch Mimikyu |
| Dragon | Mina | Catch 50 Alola Pokémon |
| Champion Stamp | Kukui | Complete the Alola Pokédex (88) |

### Galar — needs 58/96

| Badge | Leader | Requirement |
|---|---|---|
| Grass | Milo | Catch Gossifleur |
| Water | Nessa | Catch 15 Galar Pokémon |
| Fire | Kabu | Catch Sizzlipede |
| Fighting | Bea | Catch Clobbopus |
| Fairy | Opal | Catch Impidimp |
| Rock | Gordie | Catch 45 Galar Pokémon |
| Ice | Melony | Catch Snom |
| Dark | Piers | Complete the Galar Pokédex (96) |

### Paldea — needs 72/120

| Badge | Leader | Requirement |
|---|---|---|
| Bug | Katy | Catch Tarountula |
| Grass | Brassius | Catch Smoliv |
| Electric | Iono | Catch Pawmi |
| Water | Kofu | Catch 20 Paldea Pokémon |
| Normal | Larry | Catch Lechonk |
| Ghost | Ryme | Catch Greavard |
| Psychic | Tulip | Catch 55 Paldea Pokémon |
| Ice | Grusha | Complete the Paldea Pokédex (120) |

---

## Strategy

**Start with Kalos.** 44 Pokémon unlocks 8 badges — barely half of what Kanto
demands. Alola (53) and Galar (58) are next easiest.

**Chase the species badges early.** Pikachu, Charizard, Lucario, Mimikyu —
these are the easiest Pokémon in the world to find merchandise of. Each one is
a badge sitting there waiting for the region to unlock.

**New species over repeats.** 500 XP vs 100.

**The "complete the dex" badges are the real wall.** Nine of the 72 need a
full regional Pokédex. Kalos at 72 is the only one that's remotely realistic.

**Watch the yellow line.** Trainer → Regions shows every region's bar with the
unlock point marked. That's your map.

---

## The screens

```
Main Menu
├── Reverse Image Version
│   ├── Play Catch 'Em All    the camera. this is the game.
│   ├── Pokedex List          all 1025 by region, caught ones green
│   ├── Search by Name        letter grid, up/down cycles matches
│   ├── Favourites            everything you've starred
│   ├── Caught Pokemon        your dex, TAB cycles the sort
│   ├── Catch Log             every catch, newest first
│   └── Back
├── PhyAI Challenge           (coming soon)
├── Trainer Status
│   ├── Info tab              profile, level, XP, totals
│   ├── Regions tab           9 progress bars + unlock markers
│   └── Badges tab            all 72, locked ones grey
└── Data                      erase catches / erase everything
```

**Trainer → TAB** cycles Info / Regions / Badges.

---

## Buttons

| Button | Does |
|---|---|
| **ENTER** | open, confirm, star a Pokémon |
| **CANCEL** | back one step |
| **TAB** | switch tab / region, cycle sort |
| **DPAD** | move |
| **PAGELEFT** | **SCAN** (only while playing) |
| **PAGERIGHT** | back |

---

## Trainers

Create a profile from **Trainer Status**: name, city, age, gender, and a team
— **Red**, **Blue**, or **Yellow**. Your team colours the UI.

Multiple trainers can share the device. Each keeps their own catches, XP,
badges and favourites, completely separate. Switch from
**Trainer → Info → Switch / New Trainer**. In the trainer list, **TAB**
deletes (with a confirmation).

---

## Data

**Main Menu → Data**

- **Erase my catches** — wipes the current trainer's catches, XP, badges and
  favourites. Profile survives.
- **Erase EVERYTHING** — every trainer, every catch. Factory reset.

Both ask first. Neither can be undone.

Everything saves automatically and survives a reboot.

---

## A note on the badge art

The badges are drawn by the app as original geometric shapes — real names,
real gym leaders, real colours, but not Nintendo's artwork.

If you want different art, drop PNGs into `~/pokedexv5/badges/` named after
the badge (`boulder_badge.png`, `cascade_badge.png`, `melemele_trial.png`).
The app uses your file if it's there and falls back to the drawn shape if it
isn't — you don't need to supply all 72.

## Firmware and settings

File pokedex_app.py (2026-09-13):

import os
import re
os.environ['SDL_AUDIODRIVER'] = 'dummy'

import pygame
import cv2
import json
import subprocess
import requests
import math
import wave
import struct
import threading
import time
import sqlite3
from datetime import datetime
from collections import Counter
from rapidfuzz import process, fuzz
from serpapi import GoogleSearch

# ─── Config ───────────────────────────────────────────────
BASE          = '/home/arduino/pokedexv5'
SERP_API_KEY  = open(f'{BASE}/serp_key.txt').read().strip()
DB_PATH       = '/home/arduino/pokedex/pokemon_db.json'
UI_IMG_DIR    = '/home/arduino/pokedex/ui_images'
CATCH_DB      = f'{BASE}/catches.db'
CAPTURE_PATH  = f'{BASE}/capture.jpg'
BADGE_IMG_DIR = f'{BASE}/badges'

# GitHub is the image host - see upload_image() for why every free host failed.
GH_USER  = 'jzofalltrades'
GH_REPO  = 'pokedex_v1'
GH_DIR   = 'pokedex_capture'
GH_TOKEN = open(f'{BASE}/gh_token.txt').read().strip()

# Professor Oak - Claude API + local whisper.cpp speech-to-text.
# The key file is optional: if it's missing, Oak shows a friendly message
# instead of crashing, so the rest of the app still runs.
try:
    CLAUDE_KEY = open(f'{BASE}/claude_key.txt').read().strip()
except Exception:
    CLAUDE_KEY = ''
WHISPER_BIN   = '/home/arduino/whisper.cpp/build/bin/whisper-cli'
WHISPER_MODEL = '/home/arduino/whisper.cpp/models/ggml-tiny.en.bin'
OAK_WAV       = '/home/arduino/whisper.cpp/oak.wav'
# OAK_MIC is resolved at record time from find_mic(), not fixed here,
# because the two identical USB cards renumber between reboots.

# PhyAI - on-device Pokemon recognition, no internet, no API.
# Trained on Colab (MobileNetV2, transfer learning), exported to TFLite.
PHYAI_MODEL  = f'{BASE}/pokedex_phyai.tflite'
PHYAI_LABELS = f'{BASE}/labels.txt'
PHYAI_SIZE   = 160          # must match the size the model was trained at
PHYAI_CONF_THRESHOLD = 0.60 # below this, treat it as "not sure" rather than guess
# Throw animation. Off for now - the board was browning out under load and
# the animation was the visible symptom, not the cause (it costs 0.05ms/frame
# on this hardware). Flip to True once the 5V supply is sorted.
THROW_ANIM    = False
BALL_BIG      = 56   # parked / start of throw
BALL_SMALL    = 34   # landed, further away
SCORE_CUTOFF  = 85


# Trigger files (written by key_serial.py)
TRIG = {
    'scan':  '/tmp/scan_trigger',
    'back':  '/tmp/back_trigger',
    'select':'/tmp/select_trigger',
    'tab':   '/tmp/tab_trigger',
    'up':    '/tmp/up_trigger',
    'down':  '/tmp/down_trigger',
    'left':  '/tmp/left_trigger',
    'right': '/tmp/right_trigger',
    'mute':  '/tmp/mute_trigger',
}

SCREEN_W, SCREEN_H = 640, 480

# The 3D-printed bezel hides a few pixels at the edges of the panel. Rather
# than shift every draw call, the whole UI is drawn to an off-screen canvas
# and blitted inset by these margins so nothing lands under the bezel. Tune
# these if the fit changes: bigger LEFT pushes content right, etc. All in
# pixels. Set every value to 0 to disable and draw edge-to-edge again.
BEZEL_LEFT   = 28
BEZEL_RIGHT  = 6
BEZEL_TOP    = 4
BEZEL_BOTTOM = 4

BG=(12,20,44); PANEL=(20,32,66); RED=(220,50,50); ORANGE=(240,140,40)
YELLOW=(245,200,40); WHITE=(245,245,250); CYAN=(90,180,235)
GREY=(120,130,150); GREEN=(40,210,90); BLACK=(8,12,26); HILITE=(40,70,130)

TYPE_COLORS={'normal':(168,168,120),'fire':(240,128,48),'water':(104,144,240),
    'electric':(248,208,48),'grass':(120,200,80),'ice':(152,216,216),
    'fighting':(192,48,40),'poison':(160,64,160),'ground':(224,192,104),
    'flying':(168,144,240),'psychic':(248,88,136),'bug':(168,184,32),
    'rock':(184,160,56),'ghost':(112,88,152),'dragon':(112,56,248),
    'dark':(112,88,72),'steel':(184,184,208),'fairy':(238,153,172)}

STAT_LABELS=[('hp','HP'),('attack','Attack'),('defense','Defense'),
    ('special-attack','Sp.Atk'),('special-defense','Sp.Def'),('speed','Speed')]

REGIONS=['Kanto','Johto','Hoenn','Sinnoh','Unova','Kalos','Alola','Galar','Paldea']
RESULT_TABS=['Stats','Location','Evolution','Moves','Cry']

# ─── Database Manager ─────────────────────────────────────
BADGE_UNLOCK_PCT = 0.60     # catch this much of a region to unlock its badges

# Region -> (national dex start, end)
REGION_RANGE = {
    'Kanto':  (1, 151),
    'Johto':  (152, 251),
    'Hoenn':  (252, 386),
    'Sinnoh': (387, 493),
    'Unova':  (494, 649),
    'Kalos':  (650, 721),
    'Alola':  (722, 809),
    'Galar':  (810, 905),
    'Paldea': (906, 1025),
}

REGION_ORDER = ['Kanto', 'Johto', 'Hoenn', 'Sinnoh', 'Unova',
                'Kalos', 'Alola', 'Galar', 'Paldea']

# Shape vocabulary for drawing badges without any copyrighted artwork.
# octagon, droplet, bolt, flower, heart, crescent, star, globe, diamond,
# hex, shield, wing, leaf, flame, gear, snow, ring, fist, spiral, feather

# Each badge: (name, leader, shape, colour, kind, value)
#   kind 'count'   -> value = how many of this region's pokemon to catch
#   kind 'species' -> value = pokemon name (must be caught)
#   kind 'all'     -> value = None, need the whole regional dex
BADGES_BY_REGION = {
    'Kanto': [
        ('Boulder Badge',  'Brock',    'octagon',  (150, 150, 160), 'species', 'geodude'),
        ('Cascade Badge',  'Misty',    'droplet',  (90, 170, 235),  'count',   25),
        ('Thunder Badge',  'Surge',    'bolt',     (245, 200, 40),  'species', 'pikachu'),
        ('Rainbow Badge',  'Erika',    'flower',   (200, 120, 200), 'count',   75),
        ('Soul Badge',     'Koga',     'heart',    (230, 120, 170), 'species', 'gastly'),
        ('Marsh Badge',    'Sabrina',  'crescent', (240, 140, 190), 'species', 'abra'),
        ('Volcano Badge',  'Blaine',   'flame',    (235, 100, 50),  'species', 'charizard'),
        ('Earth Badge',    'Giovanni', 'globe',    (140, 190, 110), 'all',     None),
    ],
    'Johto': [
        ('Zephyr Badge',   'Falkner',  'wing',     (150, 190, 235), 'species', 'hoothoot'),
        ('Hive Badge',     'Bugsy',    'hex',      (190, 200, 60),  'species', 'ledyba'),
        ('Plain Badge',    'Whitney',  'ring',     (230, 190, 200), 'count',   20),
        ('Fog Badge',      'Morty',    'spiral',   (170, 140, 200), 'species', 'misdreavus'),
        ('Storm Badge',    'Chuck',    'fist',     (215, 90, 80),   'count',   40),
        ('Mineral Badge',  'Jasmine',  'gear',     (180, 185, 200), 'species', 'magnemite'),
        ('Glacier Badge',  'Pryce',    'snow',     (150, 215, 230), 'species', 'swinub'),
        ('Rising Badge',   'Clair',    'diamond',  (120, 100, 220), 'all',     None),
    ],
    'Hoenn': [
        ('Stone Badge',    'Roxanne',  'octagon',  (170, 150, 120), 'species', 'geodude'),
        ('Knuckle Badge',  'Brawly',   'fist',     (220, 110, 70),  'count',   25),
        ('Dynamo Badge',   'Wattson',  'bolt',     (245, 205, 60),  'species', 'electrike'),
        ('Heat Badge',     'Flannery', 'flame',    (230, 90, 60),   'species', 'numel'),
        ('Balance Badge',  'Norman',   'ring',     (200, 200, 210), 'count',   60),
        ('Feather Badge',  'Winona',   'feather',  (170, 175, 230), 'species', 'swablu'),
        ('Mind Badge',     'Tate&Liza','crescent', (230, 130, 190), 'species', 'spoink'),
        ('Rain Badge',     'Wallace',  'droplet',  (80, 165, 230),  'all',     None),
    ],
    'Sinnoh': [
        ('Coal Badge',     'Roark',    'octagon',  (130, 130, 140), 'species', 'cranidos'),
        ('Forest Badge',   'Gardenia', 'leaf',     (110, 200, 100), 'count',   25),
        ('Cobble Badge',   'Maylene',  'fist',     (215, 120, 90),  'species', 'riolu'),
        ('Fen Badge',      'Crasher',  'droplet',  (90, 175, 225),  'count',   50),
        ('Relic Badge',    'Fantina',  'spiral',   (180, 130, 210), 'species', 'drifloon'),
        ('Mine Badge',     'Byron',    'shield',   (175, 180, 195), 'species', 'shieldon'),
        ('Icicle Badge',   'Candice',  'snow',     (150, 215, 235), 'species', 'snover'),
        ('Beacon Badge',   'Volkner',  'bolt',     (245, 200, 50),  'all',     None),
    ],
    'Unova': [
        ('Trio Badge',     'Striaton', 'flower',   (200, 160, 200), 'count',   15),
        ('Basic Badge',    'Lenora',   'ring',     (190, 170, 140), 'species', 'lillipup'),
        ('Insect Badge',   'Burgh',    'hex',      (185, 200, 70),  'species', 'sewaddle'),
        ('Bolt Badge',     'Elesa',    'bolt',     (245, 205, 55),  'species', 'blitzle'),
        ('Quake Badge',    'Clay',     'diamond',  (215, 175, 110), 'count',   60),
        ('Jet Badge',      'Skyla',    'wing',     (160, 185, 235), 'species', 'ducklett'),
        ('Freeze Badge',   'Brycen',   'snow',     (145, 210, 230), 'species', 'cubchoo'),
        ('Legend Badge',   'Drayden',  'star',     (125, 95, 215),  'all',     None),
    ],
    'Kalos': [
        ('Bug Badge',      'Viola',    'hex',      (185, 200, 65),  'species', 'scatterbug'),
        ('Cliff Badge',    'Grant',    'octagon',  (160, 145, 125), 'count',   15),
        ('Rumble Badge',   'Korrina',  'fist',     (220, 115, 80),  'species', 'lucario'),
        ('Plant Badge',    'Ramos',    'leaf',     (115, 200, 95),  'species', 'chespin'),
        ('Voltage Badge',  'Clemont',  'bolt',     (245, 205, 55),  'species', 'dedenne'),
        ('Fairy Badge',    'Valerie',  'star',     (240, 165, 200), 'species', 'flabebe'),
        ('Psychic Badge',  'Olympia',  'crescent', (235, 130, 190), 'count',   45),
        ('Iceberg Badge',  'Wulfric',  'snow',     (150, 215, 235), 'all',     None),
    ],
    'Alola': [
        ('Melemele Trial', 'Ilima',    'ring',     (245, 180, 80),  'species', 'yungoos'),
        ('Akala Trial',    'Lana',     'droplet',  (85, 170, 230),  'count',   15),
        ('Fire Trial',     'Kiawe',    'flame',    (230, 95, 55),   'species', 'salandit'),
        ('Grass Trial',    'Mallow',   'leaf',     (110, 200, 100), 'species', 'fomantis'),
        ('Electric Trial', 'Sophocles','bolt',     (245, 205, 55),  'species', 'charjabug'),
        ('Ghost Trial',    'Acerola',  'spiral',   (175, 135, 205), 'species', 'mimikyu'),
        ('Dragon Trial',   'Mina',     'star',     (240, 170, 205), 'count',   50),
        ('Champion Stamp', 'Kukui',    'globe',    (140, 190, 115), 'all',     None),
    ],
    'Galar': [
        ('Grass Badge',    'Milo',     'leaf',     (110, 200, 100), 'species', 'gossifleur'),
        ('Water Badge',    'Nessa',    'droplet',  (85, 170, 230),  'count',   15),
        ('Fire Badge',     'Kabu',     'flame',    (230, 95, 55),   'species', 'sizzlipede'),
        ('Fighting Badge', 'Bea',      'fist',     (220, 115, 80),  'species', 'clobbopus'),
        ('Fairy Badge',    'Opal',     'star',     (240, 165, 200), 'species', 'impidimp'),
        ('Rock Badge',     'Gordie',   'octagon',  (165, 150, 130), 'count',   45),
        ('Ice Badge',      'Melony',   'snow',     (150, 215, 235), 'species', 'snom'),
        ('Dark Badge',     'Piers',    'crescent', (110, 90, 120),  'all',     None),
    ],
    'Paldea': [
        ('Bug Badge',      'Katy',     'hex',      (185, 200, 65),  'species', 'tarountula'),
        ('Grass Badge',    'Brassius', 'leaf',     (110, 200, 100), 'species', 'smoliv'),
        ('Electric Badge', 'Iono',     'bolt',     (245, 205, 55),  'species', 'pawmi'),
        ('Water Badge',    'Kofu',     'droplet',  (85, 170, 230),  'count',   20),
        ('Normal Badge',   'Larry',    'ring',     (195, 190, 175), 'species', 'lechonk'),
        ('Ghost Badge',    'Ryme',     'spiral',   (175, 135, 205), 'species', 'greavard'),
        ('Psychic Badge',  'Tulip',    'crescent', (235, 130, 190), 'count',   55),
        ('Ice Badge',      'Grusha',   'snow',     (150, 215, 235), 'all',     None),
    ],
}


def region_of(pid):
    for r, (lo, hi) in REGION_RANGE.items():
        if lo <= pid <= hi:
            return r
    return 'Paldea'


def region_size(region):
    lo, hi = REGION_RANGE[region]
    return hi - lo + 1


def region_progress(region, caught_ids):
    """(caught_in_region, total_in_region, fraction)"""
    lo, hi = REGION_RANGE[region]
    n = sum(1 for p in caught_ids if lo <= p <= hi)
    total = hi - lo + 1
    return n, total, (n / total if total else 0.0)


def unlock_target(region):
    """How many pokemon you actually need to unlock this region's badges.
    Rounded UP so the number shown is always the true requirement - 60% of
    Kanto is 90.6, so you need 91, not 90."""
    import math as _m
    return _m.ceil(region_size(region) * BADGE_UNLOCK_PCT)


def badges_unlocked(region, caught_ids):
    """True once you've caught unlock_target(region) of the region."""
    n, total, frac = region_progress(region, caught_ids)
    return n >= unlock_target(region)


def badge_earned(region, badge, caught_ids, caught_names):
    """Is this specific badge earned? Requires the region to be unlocked first."""
    if not badges_unlocked(region, caught_ids):
        return False
    name, leader, shape, col, kind, val = badge
    n, total, _ = region_progress(region, caught_ids)
    if kind == 'count':
        return n >= val
    if kind == 'species':
        return val in caught_names
    if kind == 'all':
        return n >= total
    return False


def badge_requirement_text(region, badge):
    name, leader, shape, col, kind, val = badge
    if kind == 'count':
        return 'Catch %d %s Pokemon' % (val, region)
    if kind == 'species':
        return 'Catch %s' % val.title()
    if kind == 'all':
        return 'Complete the %s Pokedex (%d)' % (region, region_size(region))
    return '?'


def all_badges_flat():
    out = []
    for r in REGION_ORDER:
        for b in BADGES_BY_REGION[r]:
            out.append((r, b))
    return out


def earned_badge_count(caught_ids, caught_names):
    n = 0
    for r in REGION_ORDER:
        for b in BADGES_BY_REGION[r]:
            if badge_earned(r, b, caught_ids, caught_names):
                n += 1
    return n


TOTAL_BADGES = sum(len(v) for v in BADGES_BY_REGION.values())


_badge_img_cache = {}


def badge_image(name, size, region=None):
    """Look for a user-supplied badge PNG. None if there isn't one.

    Checks the region subfolder first, then the flat folder:
        badges/kalos/fairy_badge.png     <- region-specific
        badges/fairy_badge.png           <- shared fallback

    Badge names repeat across regions (Kalos and Galar both have a Fairy
    Badge; Galar and Paldea share Grass/Water/Fire/Ice), so the subfolder is
    what keeps them apart. The flat path stays supported so older setups that
    dumped everything in one folder keep working.
    """
    key = (name, size, region)
    if key in _badge_img_cache:
        return _badge_img_cache[key]
    fn = name.lower().replace(' ', '_').replace('&', '') + '.png'
    paths = []
    if region:
        paths.append(os.path.join(BADGE_IMG_DIR, region.lower(), fn))
    paths.append(os.path.join(BADGE_IMG_DIR, fn))
    img = None
    for path in paths:
        if os.path.exists(path):
            try:
                img = pygame.image.load(path).convert_alpha()
                img = pygame.transform.smoothscale(img, (size, size))
                break
            except Exception:
                img = None
    _badge_img_cache[key] = img
    return img


def _poly(cx, cy, r, n, rot=0.0):
    return [(cx + r*math.cos(rot + i*2*math.pi/n),
             cy + r*math.sin(rot + i*2*math.pi/n)) for i in range(n)]


def _star_pts(cx, cy, r, points=5, inner=0.45):
    pts = []
    for i in range(points*2):
        a = -math.pi/2 + i*math.pi/points
        rad = r if i % 2 == 0 else r*inner
        pts.append((cx + rad*math.cos(a), cy + rad*math.sin(a)))
    return pts
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

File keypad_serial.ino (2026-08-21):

// keypad_serial.ino
// ESP32-C3 Super Mini - 9 direct push buttons over USB serial.
//
// IMPORTANT: Arduino IDE -> Tools -> USB CDC On Boot -> Enabled  before flashing.
// Each button: one leg -> GPIO, other leg -> GND. Internal pull-ups used.
//
// Button roles in the app:
//   enter     = SELECT (open menu item)
//   cancel    = BACK
//   pageleft  = SCAN (gameplay)
//   pageright = BACK
//   tab       = switch tab / region
//   up/down/left/right = navigation
//
// GPIO 2 is a strapping pin; if "tab" misbehaves move it to GPIO 21.

const int NUM_BTN = 9;
int btnPins[NUM_BTN] = {0, 1, 2, 3, 4, 5, 6, 7, 10};
const char* btnKeys[NUM_BTN] = {
  "enter",     // GPIO 0  - SELECT
  "cancel",    // GPIO 1  - BACK
  "tab",       // GPIO 2  - TAB
  "up",        // GPIO 3
  "down",      // GPIO 4
  "right",     // GPIO 5
  "left",      // GPIO 6
  "pageleft",  // GPIO 7  - SCAN
  "pageright"  // GPIO 10 - BACK
};

bool lastState[NUM_BTN];

void setup() {
  Serial.begin(115200);
  for (int i = 0; i < NUM_BTN; i++) {
    pinMode(btnPins[i], INPUT_PULLUP);
    lastState[i] = HIGH;
  }
}

void loop() {
  for (int i = 0; i < NUM_BTN; i++) {
    bool state = digitalRead(btnPins[i]);
    if (lastState[i] == HIGH && state == LOW) {
      Serial.println(btnKeys[i]);
      delay(50);  // debounce
    }
    lastState[i] = state;
  }
  delay(10);
}

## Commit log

2026-08-23 Update build guide CAD link and games app
2026-08-23 Add CAD files + full README; update build guide and games app
    [BackPlate.stl, Cap_Back.stl, Cap_DPad.stl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]
2026-08-25 Add full system schematic to build guide
2026-09-13 Log Oak API errors to help diagnose failures
    [pokedex_app.py]
2026-09-16 Add full CAD set (3mf, f3d, fbx, glb, obj, step, stl) under CAD/
    [BackPlate.3mf, BackPlate.stl, Cap_Back.3mf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]
